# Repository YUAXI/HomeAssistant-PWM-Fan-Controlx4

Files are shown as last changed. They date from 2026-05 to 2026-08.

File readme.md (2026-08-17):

# HomeAssistant-PWM-Fan-Controlx4

<p align="center"><a href="readme.md">中文</a> · <a href="README_EN.md">English</a></p>

一个基于 ESPHome 的 4 路 PWM 风扇控制器，支持 Home Assistant、Web 控制面板和 HTTP REST API。每路风扇都可以独立开关、调速和读取转速；v2.0 固件还支持 DS18B20 温度控制及 LD2402G 毫米波雷达扩展。

## 1. 固件版本与下载

### 1.1 先确认硬件版本

刷写前请先确认主控硬件与固件匹配：

> **成品设备通常采用单核设计，只能刷入 `v1.0 单核` 或任意 `v2.0` 固件。请勿将 `v1.0 双核` 固件刷入单核设备，否则设备将无法启动。**

### 1.2 固件选择

| 固件版本 | 处理器 | 主要功能 | 适用场景 |
|:---|:---:|:---|:---|
| **v1.0 双核** | 双核 | 4 路风扇控制、转速显示、Web、HTTP API、诊断、BLE Proxy | 确认使用双核硬件，且需要较高性能 |
| **v1.0 单核** | 单核 | 4 路风扇控制、转速显示、Web、HTTP API、诊断、BLE Proxy | v1.0 单核硬件，使用 HA 自动化控温 |
| **v2.0 Basic** | 单核 | 基础 4 路风扇控制、转速显示、Web、HTTP API、诊断、BLE Proxy | v2.0 硬件，不使用本地温度和雷达 |
| **v2.0 DS18B20** | 单核 | v2.0 Basic 功能 + 最多 4 个 DS18B20 温度传感器 + 本地自动调速 | 服务器、机柜、NAS 等需要脱离 HA 独立控温的场景 |
| **v2.0 DS18B20+雷达** | 单核 | DS18B20 版本功能 + LD2402G 24GHz 毫米波人体存在检测 | 需要按人体存在状态联动的智能家居场景 |

所有版本均支持：

- 4 路风扇独立 PWM 调速，速度范围为 1-100%，支持完全断电停转。
- 4 路风扇转速（RPM）读取。
- Home Assistant ESPHome 集成、Web 控制面板和 HTTP REST API。
- 运行时间、Wi-Fi 信号、IP 地址、SSID 和 ESPHome 版本等诊断实体。
- 蓝牙代理（BLE Proxy），用于扩展 Home Assistant 的蓝牙覆盖范围。

### 1.3 功能对比

| 功能 | v1.0 双核 | v1.0 单核 | v2.0 Basic | v2.0 DS18B20 | v2.0 + 雷达 |
|:-----|:---:|:---:|:---:|:---:|:---:|
| 4 路 PWM 风扇控制 | ✅ | ✅ | ✅ | ✅ | ✅ |
| 完全断电停转 | ✅ | ✅ | ✅ | ✅ | ✅ |
| 实时转速显示 | ✅ | ✅ | ✅ | ✅ | ✅ |
| Web 界面 / HTTP API | ✅ | ✅ | ✅ | ✅ | ✅ |
| 诊断实体 | ✅ | ✅ | ✅ | ✅ | ✅ |
| 蓝牙代理 | ✅ | ✅ | ✅ | ✅ | ✅ |
| DS18B20 温度控制 | - | - | - | ✅ | ✅ |
| LD2402G 毫米波雷达 | - | - | - | - | ✅ |

### 1.4 下载预编译固件

固件由 GitHub Actions 自动编译并发布，无需手动打包：

[前往 GitHub Releases 下载](https://github.com/YUAXI/HomeAssistant-PWM-Fan-Controlx4/releases)

每个版本包含以下 3 类文件：

| 文件后缀 | 用途 |
|:---|:-----|
| `.firmware.bin` | 常规刷写使用的标准固件 |
| `.firmware.factory.bin` | 完整恢复出厂设置时使用的工厂固件 |
| `.firmware.ota.bin` | 已联网设备的 OTA 升级固件 |

Release 中的版本名称与配置文件对应关系如下：

| Release 名称 | 配置文件 |
|:---|:---|
| `v1.0-dual-core` | `firmware/v1.0/dual-core/config.yaml` |
| `v1.0-single-core` | `firmware/v1.0/single-core/config.yaml` |
| `v2.0-basic` | `firmware/v2.0/single-core/basic/config.yaml` |
| `v2.0-ds18b20` | `firmware/v2.0/single-core/ds18b20/config.yaml` |
| `v2.0-ds18b20-radar` | `firmware/v2.0/single-core/ds18b20-radar/config.yaml` |

### 1.5 自定义编译

需要修改 Wi-Fi、实体名称或其他 ESPHome 配置时，可以直接编辑上表中的 `config.yaml`，然后使用 ESPHome 编译和刷写。所有配置文件都使用 ESP32 DevKit、ESP-IDF 框架；v1.0 单核和 v2.0 固件明确启用了单核运行配置。

## 2. 快速上手

### 2.1 供电

| 供电方式 | 接口 | 电压 | 说明 |
|:---|:-----|:-----|:-----|
| **DC 接口（推荐）** | DC 座 | 12V / 2A 以上 | 正常运行，同时为风扇和 ESP32 供电 |
| Type-C 接口 | USB-C | 5V | 仅用于刷写和调试，不能驱动风扇正常工作 |

### 2.2 首次配网

设备上电后会创建无密码 Wi-Fi 热点 `ESP32-Fan-22810`：

1. 使用手机或电脑连接 `ESP32-Fan-22810`。
2. 浏览器访问 `http://192.168.4.1` 或 `http://esp32pwm22810.local`。
3. 在 Wi-Fi 配置向导中选择目标 Wi-Fi 并输入密码。
4. 设备连接成功后会自动重启。

如果需要跳过首次配网，可以在刷写前于配置文件中预设 `wifi.ssid` 和 `wifi.password`。

### 2.3 刷写固件

使用 Type-C 连接设备和电脑，选择对应硬件的固件，使用 ESPHome 刷写工具或 `esptool` 完成首次刷写。设备联网后可以使用 `.firmware.ota.bin` 进行远程升级。

### 2.4 接入 Home Assistant

先确保已安装 Home Assistant 的 ESPHome 集成：

1. 打开 **设置 → 设备与服务 → 添加集成**，搜索 **ESPHome**。
2. 选择自动发现的 `ESP32 PWM 22810`，或手动输入设备 IP 地址。
3. 输入以下配置文件中的 API 加密密钥并提交：

   ```text
   LqGIGJ3qyRc+6X6hsMe5vAms+Jyh2lOMh1FQu8yyuzk=
   ```

接入后通常会出现以下实体：

| 实体类型 | 数量 | 说明 |
|:---|:----:|:-----|
| 风扇 | 4 个 | 独立开关和 1-100% 调速 |
| 转速传感器 | 4 个 | 单位为 RPM |
| 温度传感器 | 4 个 | 仅 v2.0 DS18B20 及雷达固件，名称为温度 A/B/C/D |
| 蓝牙代理 | 1 个 | BLE Proxy 节点 |
| 诊断实体 | 若干 | 运行时间、Wi-Fi 信号、IP、SSID、ESPHome 版本等 |

### 2.5 Web 控制面板

浏览器访问 `http://设备IP` 即可打开 Web 控制面板，不依赖 Home Assistant。面板可以查看 4 路风扇状态、独立调节风速并查看设备运行信息。

## 3. v2.0 温度与雷达功能

### 3.1 DS18B20 接线

DS18B20 接入 v2.0 板载 **GPIO14** 的 3PIN 排针，使用 1-Wire 总线：

| DS18B20 引脚 | 连接位置 |
|:---:|:---|
| VCC | 3.3V 或 5V |
| GND | GND |
| DATA | GPIO14 |

配置已集成上拉电阻，GPIO14 总线最多可并联 4 个 DS18B20。固件按总线索引将其命名为 **温度 A、温度 B、温度 C、温度 D**。

### 3.2 本地温度调速

本节适用于 `v2.0-ds18b20` 和 `v2.0-ds18b20-radar` 固件。接入设备后，在 Home Assistant 的 **ESP32 PWM 22810** 设备页面中，为每路风扇设置温度源和参数：

| 参数 | 作用 | 默认值 |
|:-----|:-----|:---:|
| 温度源绑定 `F-Src` | 选择未绑定或温度 A/B/C/D | 风扇 1-4 分别绑定 A-D |
| 启控温度 `T-Min` | 温度低于或等于该值时断电停转 | 30°C |
| 满载温度 `T-Max` | 温度高于或等于该值时使用最高风速 | 50°C |
| 最低风速 `F-Min` | 线性调速区间的最低风速 | 0% |
| 最高风速 `F-Max` | 线性调速区间的最高风速 | 100% |

控制逻辑：

```text
温度 ≤ T-Min                   → 断电完全关停风扇
T-Min < 温度 < T-Max           → 按温度线性比例调速
温度 ≥ T-Max                   → 以 F-Max 运行
温度读取异常                    → 保持当前风速和运行状态
```

上述参数支持掉电保持。未绑定温度源的风扇不会执行本地温控逻辑，仍可通过 Home Assistant、Web 或 HTTP API 手动控制。

### 3.3 LD2402G 雷达接口

仅 `v2.0-ds18b20-radar` 固件启用雷达串口：

| 雷达接口 | 控制器接口 |
|:---|:---|
| TX | GPIO4（UART RX） |
| RX | GPIO5（UART TX） |
| 电源 / 地 | v2.0 开发者排针的 5V / GND |

串口速率为 `115200`。雷达固件提供目标存在状态和目标距离实体，并提供最近、最远距离过滤参数，默认范围为 `0.10-1.5 m`。雷达与风扇、温度控制的联动关系可在 Home Assistant 中通过自动化配置。

## 4. Home Assistant 自动化控温

v2.0 DS18B20 固件已经支持本地温控；以下方式适用于所有版本，尤其适合 v1.0，或需要使用 CPU 温度、环境温度等 Home Assistant 外部温度源的场景。

### 4.1 配置步骤

1. 打开 Home Assistant → **自动化与场景 → 创建自动化**。
2. 点击右上角 **更多 → YAML 编辑**。
3. 粘贴下方模板。
4. 将温度传感器和风扇实体 ID 替换为自己的实体后保存。

### 4.2 YAML 模板

```yaml
alias: "通用智能风扇线性调速"
description: "根据温度传感器数值线性控制风扇 PWM 占空比"
mode: restart

trigger:
  - platform: state
    entity_id: sensor.nas_temperature_x86_pkg_temp  # 需要修改

condition:
  - condition: template
    value_template: "{{ is_number(states('sensor.nas_temperature_x86_pkg_temp')) }}"  # 需要修改

action:
  - service: fan.set_percentage
    target:
      entity_id: fan.fan_1  # 需要修改
    data:
      percentage: >
        {% set current_temp = states('sensor.nas_temperature_x86_pkg_temp') | float(0) %}  {# 需要修改 #}
        {% set t_min = 30 %}
        {% set t_max = 50 %}
        {% set f_min = 0 %}
        {% set f_max = 100 %}
        {% if current_temp <= t_min %}
          {{ f_min }}
        {% elif current_temp >= t_max %}
          {{ f_max }}
        {% else %}
          {% set result = ((current_temp - t_min) * (f_max - f_min) / (t_max - t_min) + f_min) %}
          {{ result | round(0) | int }}
        {% endif %}
```

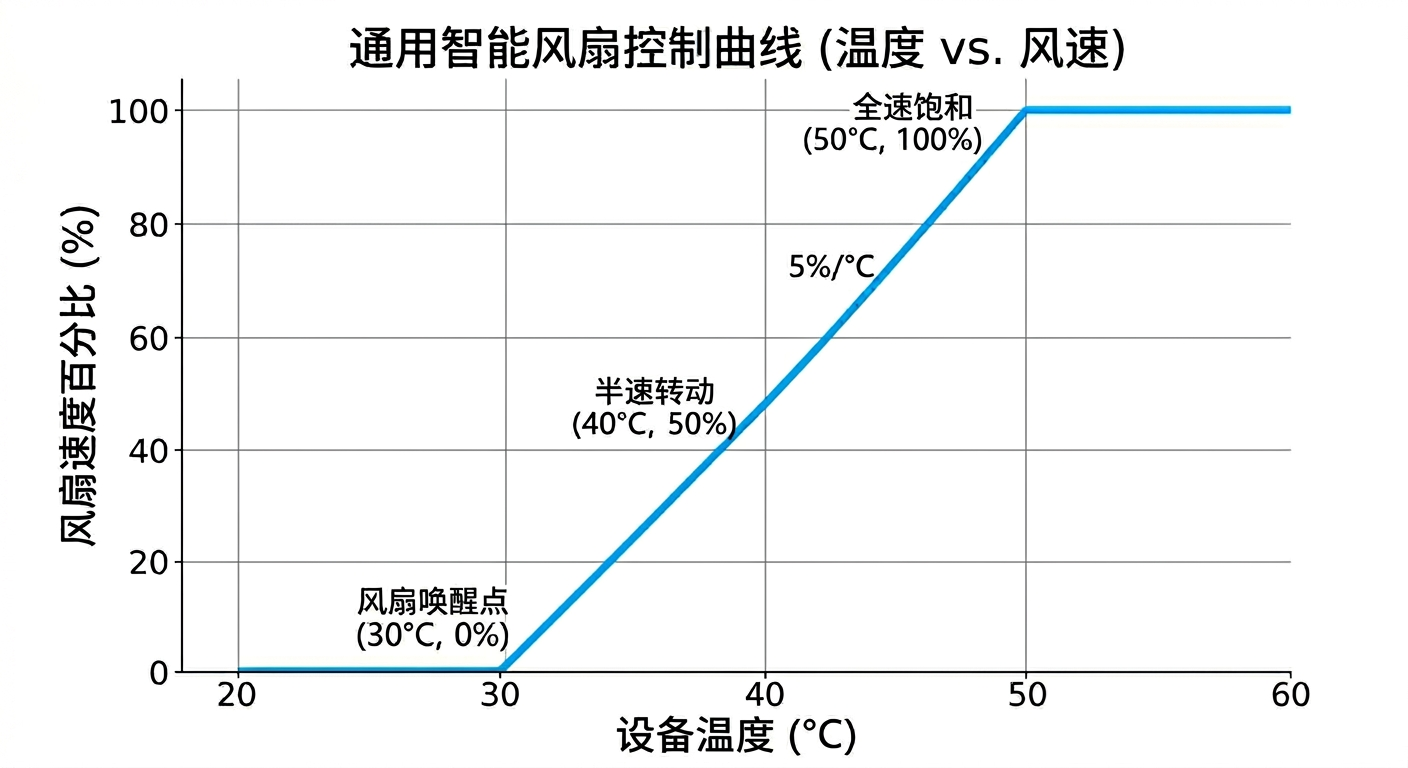
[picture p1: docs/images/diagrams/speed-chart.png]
温度与风速关系


常见温度源示例：

| 温度来源 | 获取方式 | 示例实体 ID |
|:---|:---|:---|
| 电脑 / 服务器 CPU | Glances 集成 | `sensor.nas_temperature_x86_pkg_temp` |
| 温湿度传感器 | Zigbee2MQTT / ZHA | `sensor.temperature_humidity_sensor_temperature` |
| 空调 / 暖气 | 智能空调集成 | `climate.living_air_conditioner` |
| 群晖 NAS | Synology DSM 集成 | `sensor.synology_disk_1_temperature` |
| 其他 ESPHome 设备 | ESPHome 集成 | 按实际设备填写 |

## 5. HTTP REST API

项目内置 Web Server，可以通过局域网 HTTP 请求控制风扇或读取传感器。控制命令使用 **POST**，状态读取使用 **GET**。实体名称包含中文时，URL 必须进行 UTF-8 编码。

### 5.1 实体与路径示例

ESPHome 会根据配置中的 `name` 自动生成实体 ID。以下为第 1 路风扇示例：

| 实体名称 | entity_id | URL 路径 |
|:---|:---|:---|
| 风扇 1 | `fan.风扇_1` | `/fan/%E9%A3%8E%E6%89%87_1` |
| 风扇 1 转速 | `sensor.风扇_1_转速` | `/sensor/%E9%A3%8E%E6%89%87_1_%E8%BD%AC%E9%80%9F` |

如需调用其他风扇，请按配置中的实体名称替换路径。也可以优先使用 Home Assistant 的 `fan.set_percentage` 服务，避免手动处理中文 URL。

### 5.2 Python 示例

```python
import requests
from urllib.parse import quote

base = "http://10.0.20.83"  # 替换为设备 IP

# 开启 2 号风扇并设置为 50%
requests.post(f"{base}/fan/{quote('风扇 2')}/turn_on", params={"speed_level": 50})

# 关闭 2 号风扇
requests.post(f"{base}/fan/{quote('风扇 2')}/turn_off")

# 读取 1 号风扇转速
response = requests.get(f"{base}/sensor/{quote('风扇 1 转速')}")
if response.status_code == 200:
    print("当前转速:", response.json()["value"])
```

## 6. 硬件资料与接口

### 6.1 硬件文件

v2.0 为推荐硬件版本：

| 类型 | v2.0 文件 | v1.0 文件 |
|:-----|:---|:---|
| PCB Gerber | [gerber.zip](./hardware/v2.0/pcb/gerber.zip) | [gerber.zip](./hardware/v1.0/pcb/gerber.zip) |
| BOM 清单 | [bom.xlsx](./hardware/v2.0/pcb/bom.xlsx) | [bom.xlsx](./hardware/v1.0/pcb/bom.xlsx) |
| 立创 EDA 工程 | [project.epro2](./hardware/v2.0/pcb/project.epro2) | [project.epro2](./hardware/v1.0/pcb/project.epro2) |
| 外壳主体 | [case.STEP](./hardware/v2.0/3d-models/print/case.STEP) | [case.step](./hardware/v1.0/3d-models/print/case.step) |
| 上盖 | [top-cover.STEP](./hardware/v2.0/3d-models/print/top-cover.STEP) | [top-cover.step](./hardware/v1.0/3d-models/print/top-cover.step) |

### 6.2 风扇接口映射

| 风扇 | PWM 输出 | Tach 转速输入 | 电源管理 |
|:----:|:---:|:---:|:---:|
| Fan1 | GPIO16 | GPIO32 | GPIO21 |
| Fan2 | GPIO17 | GPIO33 | GPIO22 |
| Fan3 | GPIO18 | GPIO25 | GPIO23 |
| Fan4 | GPIO19 | GPIO26 | GPIO13 |

v2.0 额外接口：

| 接口 | 说明 |
|:-----|:-----|
| GPIO14（3PIN 排针） | DS18B20 1-Wire 温度总线 |
| 4PIN 开发者排针（5V / GND / GPIO5 / GPIO4） | 可扩展 LD2402G 雷达、RS485 等外设 |

### 6.3 硬件设计要点

- **风扇电源控制**：使用 `TPS22810DBVR` 直接切断风扇供电，实现真正的完全停转。
- **电源方案**：12V → 5V（`TPS5430DDAR` DC-DC）→ 3.3V（`AMS1117-3.3`）。
- **USB 转串口**：板载 `CH340C`，通过 Type-C 连接电脑刷写和调试。

## 7. 项目展示

<div style="text-align: center;">
  <table>
    <tr>
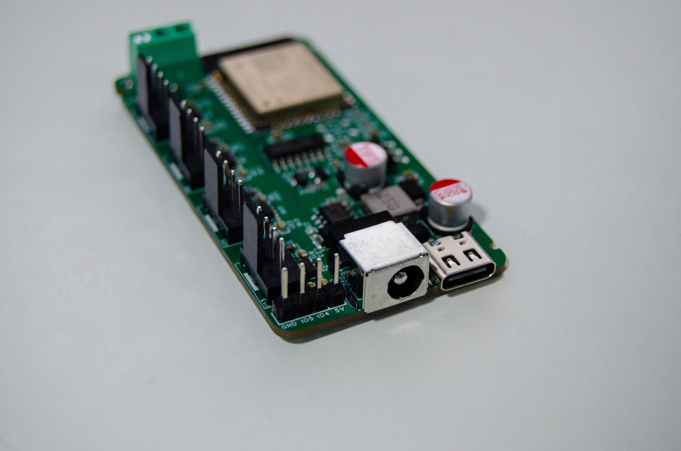
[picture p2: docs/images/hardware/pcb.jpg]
PCB 实物图
      <td width="25%" style="padding: 10px;"></td>
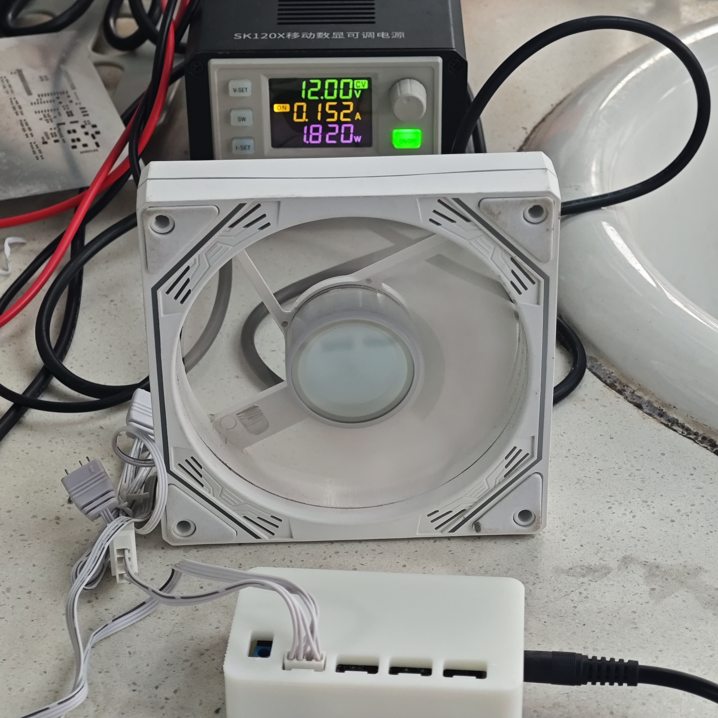
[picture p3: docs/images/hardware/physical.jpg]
测试图
      <td width="25%" style="padding: 10px;"></td>
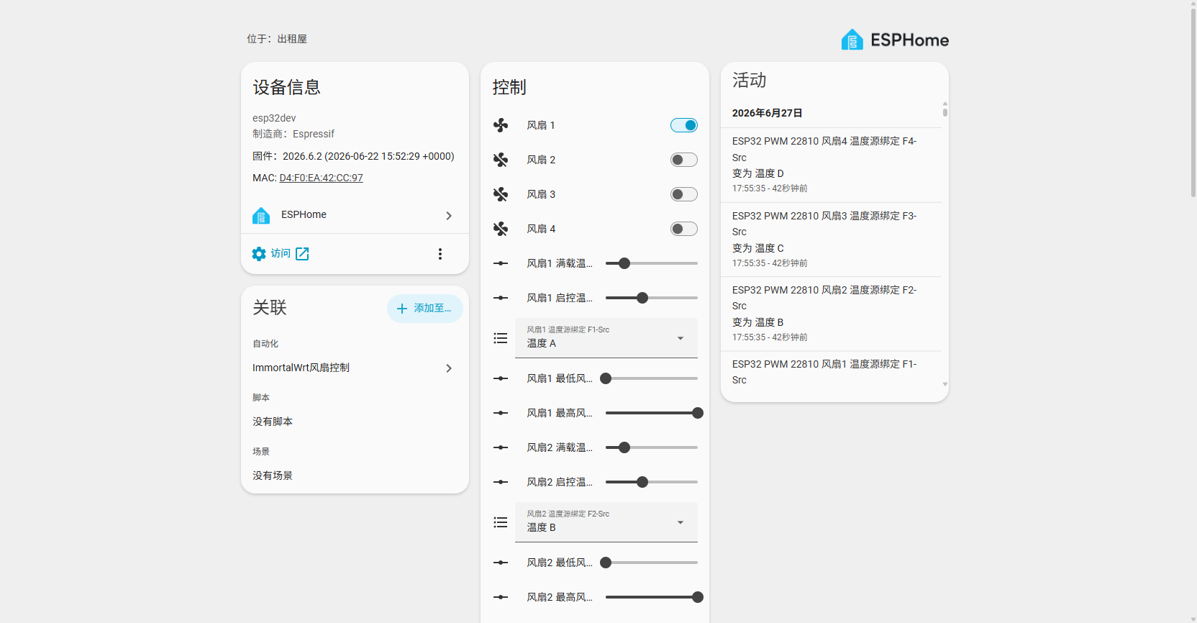
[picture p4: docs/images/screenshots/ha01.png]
Home Assistant 控制界面
      <td width="25%" style="padding: 10px;"></td>
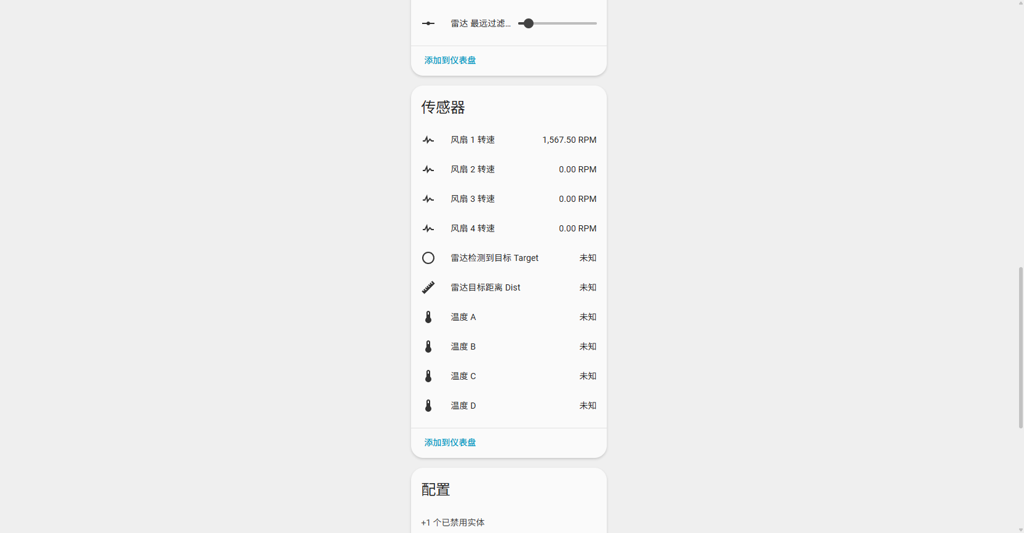
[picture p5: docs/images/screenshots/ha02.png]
Home Assistant 设备诊断信息
      <td width="25%" style="padding: 10px;"></td>
    </tr>
  </table>
</div>

## 8. 更新记录

| 日期 | 更新内容 |
|:-----|:---|
| 2026-08-16 | 自动调速时温度低于或等于 `T-Min` 时断电停转，温度恢复后自动重启风扇。 |
| 2026-07-10 | DS18B20 读取异常时保持当前风速，移除异常时强制全速保护。 |
| 2026-07-01 | 全版本增加蓝牙代理；CI 自动编译并发布 Release；移除仓库中的预编译固件。 |
| v2.0 | 增加 DS18B20 温度控制、毫米波雷达固件和 v2.0 硬件设计。 |
| v1.0 | 提供 Web 界面、HTTP REST API 和诊断实体。 |

## 9. 支持与许可证

交流群二维码不再维护。

<div style="text-align: center;">
  <table>
    <tr>
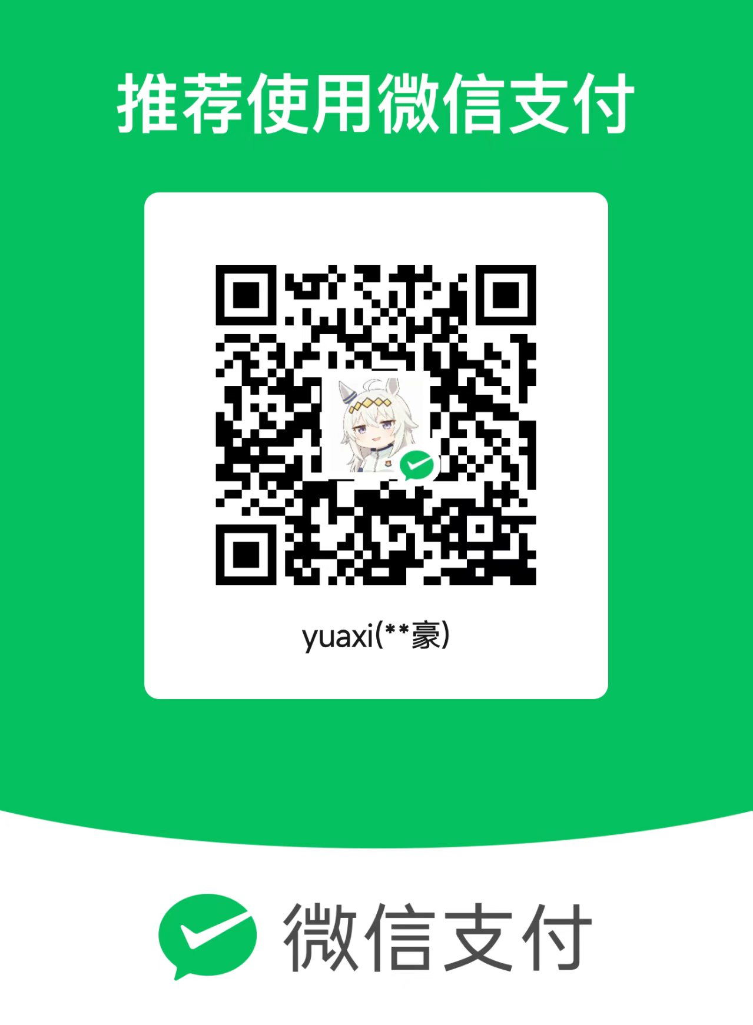
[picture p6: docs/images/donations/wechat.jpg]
微信打赏
      <td width="50%" style="padding: 10px;"><p><small>微信</small></p></td>
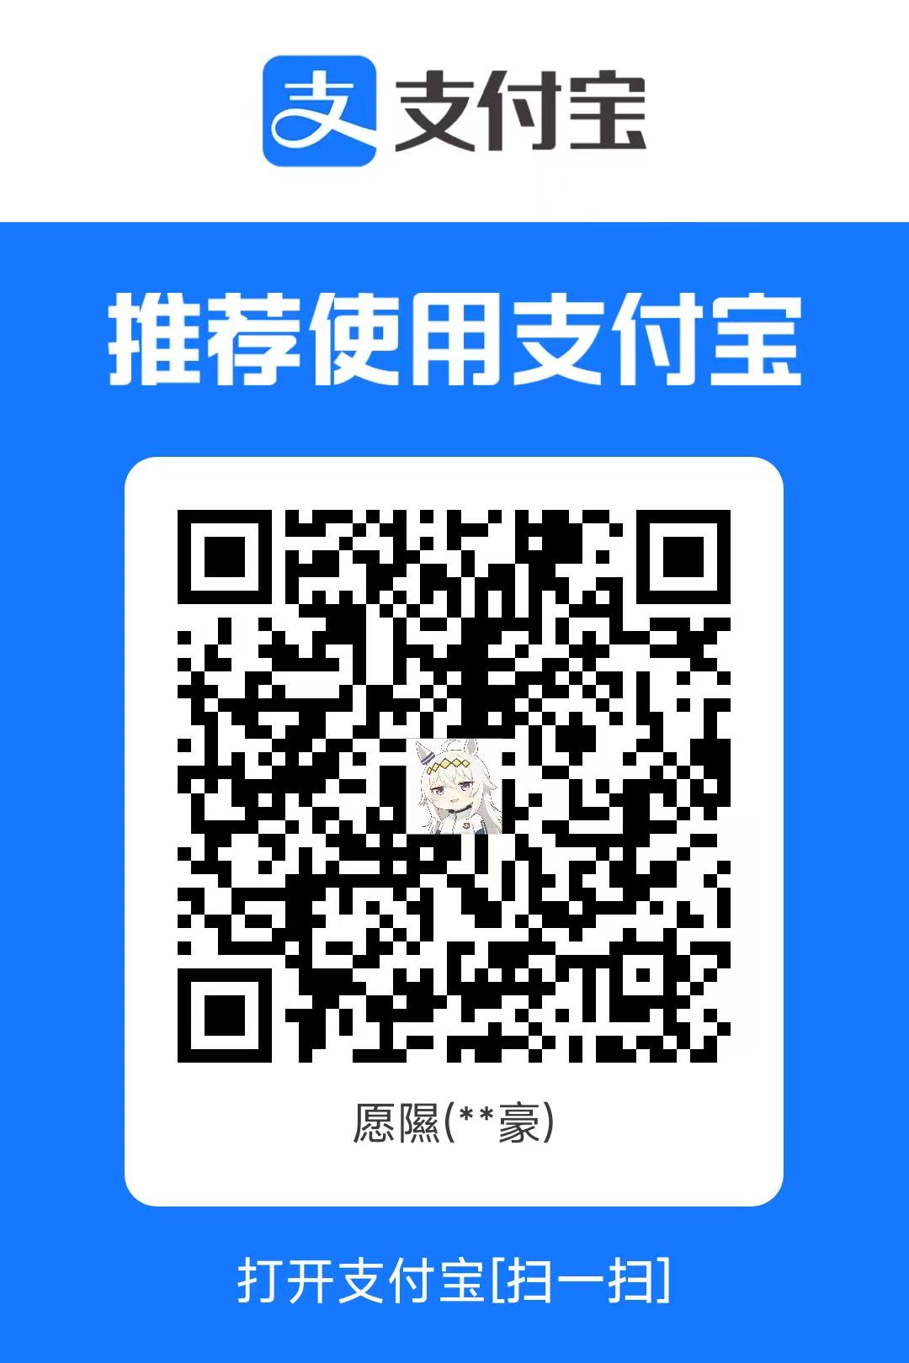
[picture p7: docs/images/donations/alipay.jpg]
支付宝打赏
      <td width="50%" style="padding: 10px;"><p><small>支付宝</small></p></td>
    </tr>
  </table>
</div>

本项目采用 [MIT License](./LICENSE) 开源许可证。

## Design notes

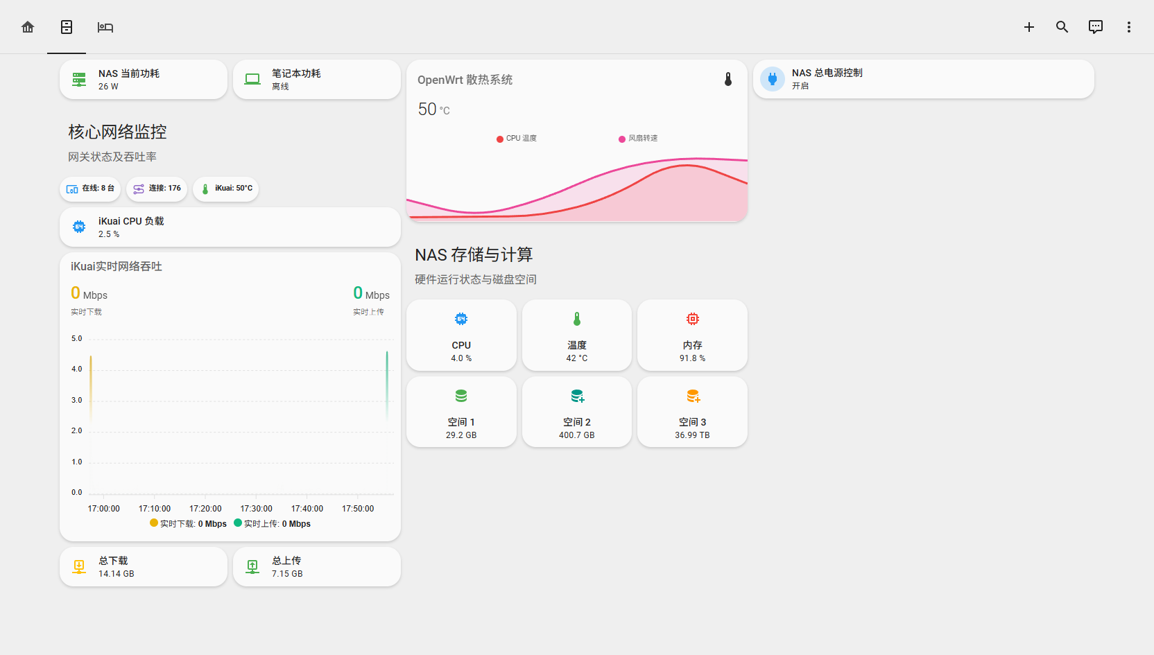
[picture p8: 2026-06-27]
docs/images/screenshots/ha03.png

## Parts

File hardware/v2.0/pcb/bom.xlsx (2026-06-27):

No. | Quantity | Comment | Designator | Footprint | Value | Manufacturer Part | Manufacturer | Supplier Part | Supplier
1 | 1 | 10nF | C1 | C0603 | 10nF | 0603B103K500NT | FH(风华) | C57112 | LCSC
2 | 2 | 220uF | C2,C12 | CAP-SMD_BD6.3-L6.6-W6.6-LS7.2-FD | 220uF | PM101M016E058PTR | CapXon(丰宾) | C2858381 | LCSC
3 | 5 | 10uF | C3,C4,C6,C9,C10 | C0603 | 10uF | CL10A106MA8NRNC | SAMSUNG(三星) | C96446 | LCSC
4 | 17 | 100nF | C5,C7,C8,C11,C13,C14,C15,C16,C17,C18,C19,C20,C21,C22,C23,C24,C25 | C0603 | 100nF | CC0603KRX7R9BB104 | YAGEO(国巨) | C14663 | LCSC
5 | 3 | SS34 | D1,D2,D3 | SMA_L4.3-W2.6-LS5.2-RD |  | SS34 | MDD(辰达半导体) | C8678 | LCSC
6 | 1 | DC-044A-A200 | DC1 | DC-IN-TH_DC-044A-20A |  | DC-044A-A200 | XUNPU(讯普) | C720575 | LCSC
7 | 1 | HDR-M_2.54_1x4P | H1 | HDR-TH_4P-P2.54-V-M |  |  |  | C492403
8 | 2 | S8050(0.5A) | Q4,Q6 | SOT-23-3_L2.9-W1.3-P1.90-LS2.4-BR |  | S8050(0.5A) | EIC | C3014350 | LCSC
9 | 13 | 10kΩ | R1,R2,R3,R5,R6,R7,R8,R9,R10,R11,R12,R13,R14 | R0603 | 10kΩ | 0603WAF1002T5E | UNI-ROYAL(厚声) | C25804 | LCSC
10 | 2 | 3.24K | R4,R15 | R0603 | 3.24K
11 | 2 | TS-1088-AR02016 | SW1,SW2 | SW-SMD_L3.9-W3.0-P4.45 |  | TS-1088-AR02016 | XUNPU(讯普) | C720477 | LCSC
12 | 1 | TPS5430DDAR | U1 | ESOP-8_L4.9-W3.9-P1.27-LS6.0-TL-EP |  | TPS5430DDAR | TI(德州仪器) | C9864 | LCSC
13 | 1 | AMS1117-3.3 | U2 | SOT-223-3_L6.5-W3.5-P3.05-LS7.0 |  | AMS1117-3.3 | TWGMC(台湾迪嘉) | C5250992 | LCSC
14 | 1 | 15uH | U3 | IND-SMD_L7.2-W6.6_GPSR07X0 | 15uH | CYA0650-22UH | SHOU HAN(首韩) |  | LCSC
15 | 1 | ESP32-WROOM-32-N4 | U4 | WIFIM-SMD_ESP32-WROOM-32-N4 |  | ESP32-WROOM-32-N4 | ESPRESSIF(乐鑫) | C82899 | LCSC
16 | 1 | CH340C | U5 | SOP-16_L10.0-W3.9-P1.27-LS6.0-BL |  | CH340C | WCH(南京沁恒) | C84681 | LCSC
17 | 4 | TPS22810DBVR | U6,U8,U10,U12 | SOT-23-6_L2.9-W1.6-P0.95-LS2.8-BL |  | TPS22810DBVR | TI(德州仪器) | C205990 | LCSC
18 | 4 | 风扇4Pin插座 | U7,U9,U11,U13 | 风扇4PIN
19 | 1 | DB301V-3.5-3P-GN-S | U14 | CONN-TH_DB301V-3.5-3P-GN |  | DB301V-3.5-3P-GN-S | DORABO(地博电气) | C695630 | LCSC
20 | 1 | TYPE-C 16PIN 2MD(073) | USB1 | USB-C-SMD_TYPE-C-6PIN-2MD-073 |  | TYPE-C 16PIN 2MD(073) | SHOU HAN(首韩) | C2765186 | LCSC

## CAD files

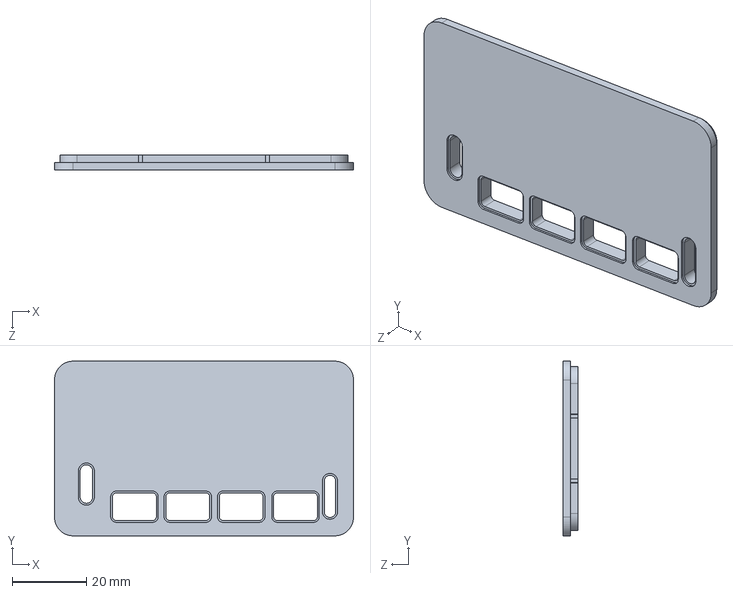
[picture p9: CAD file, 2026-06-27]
hardware/v2.0/3d-models/print/top-cover.STEP
80.4 x 47.0 x 4.00 mm

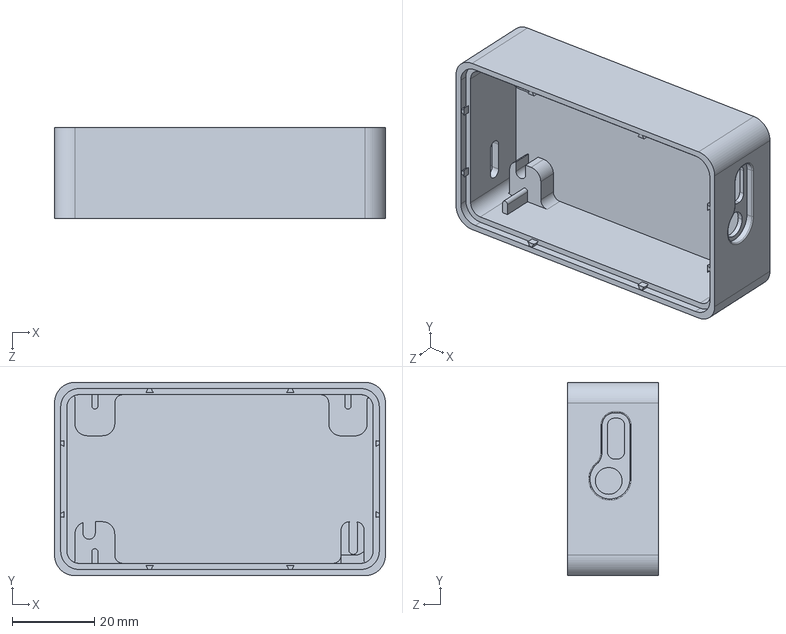
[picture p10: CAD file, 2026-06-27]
hardware/v2.0/3d-models/print/case.STEP
80.4 x 47.0 x 22.0 mm

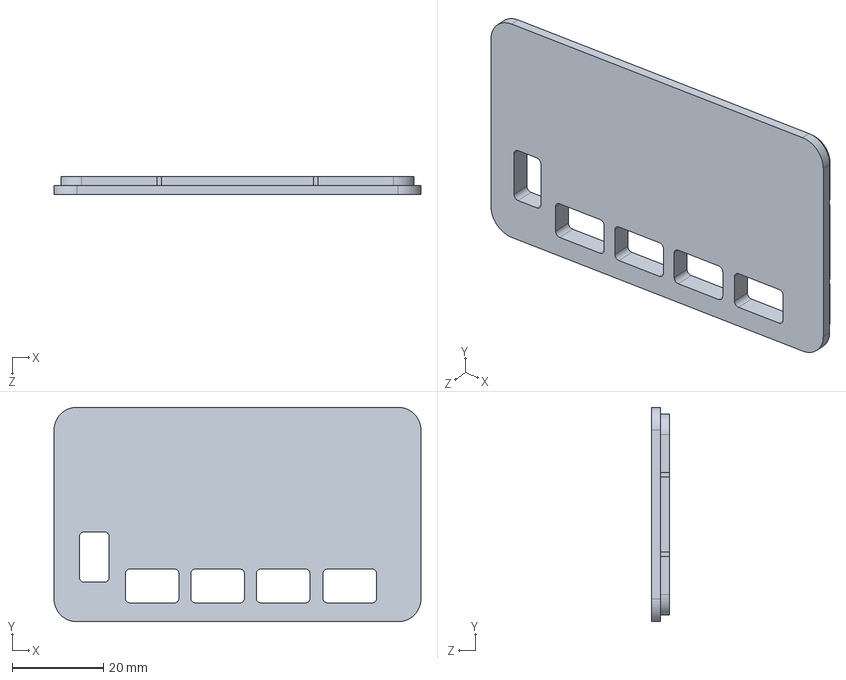
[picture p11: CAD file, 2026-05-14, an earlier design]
hardware/v1.0/3d-models/print/top-cover.step
80.4 x 47.0 x 4.00 mm

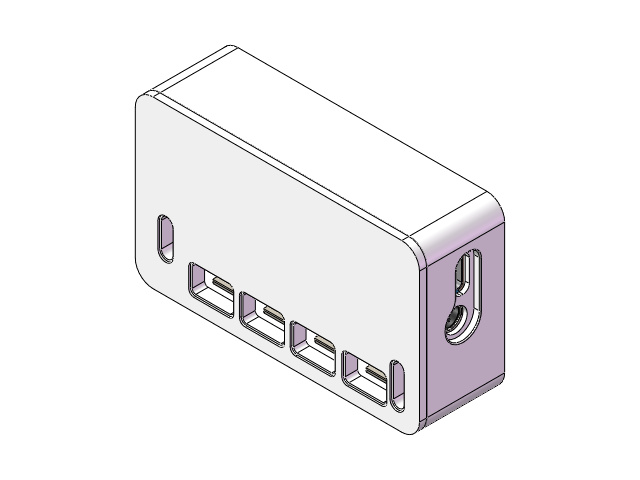
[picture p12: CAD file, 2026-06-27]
hardware/v2.0/3d-models/source/assembly.SLDASM
top-cover
case
CAP-SMD_BD6.3-L6.6-W6.6-LS7.2-FD~CAP-SMD_BD6.3-L6.6-W6.6-LS7.2-FD~qhwz.step x 2
IND-SMD_L7.2-W6.6_GPSR07X0~IND-SMD_L7.2-W6.6-H3.0_GPSR07X0~RW3T.step
ESOP-8_L4.9-W3.9-P1.27-LS6.0-TL-EP~ESOP-8_L4.9-W3.9-P1.27-LS6.0-TL-EP~MRIl.step
DC-IN-TH_DC-044A-20A~DC-IN-TH_DC-044A-20A~IdZU.step
SOT-223-3_L6.5-W3.5-P3.05-LS7.0~SOT-223-3_L6.5-W3.5-P3.05-LS7.0~3Vlb.step
R0603~R0603~Ejyd.step x 15
USB-C-SMD_TYPE-C-6PIN-2MD-073~USB-C-SMD_TYPE-C-6PIN-2MD-073~PAtE.step
C0603~C0603_L1.6-W0.8-H0.8~XpD2.step x 23
SMA_L4.3-W2.6-LS5.2-RD~SMA_L4.3-W2.6-LS5.2-RD~yZNh.step x 3
HDR-TH_4P-P2.54-V-M~HDR-TH_4P-P2.54-M-LI-1X4P~ZgB5.step
SOT-23-3_L2.9-W1.3-P1.90-LS2.4-BR~SOT-23-3P_L2.9-W1.3-H1.0-LS2.4-P0.95~SnWO.step x 2
SOT-23-6_L2.9-W1.6-P0.95-LS2.8-BL~SOT-23-6_L2.9-W1.6-H1.5-LS2.8-P0.95~LPVG.step x 4
SW-SMD_L3.9-W3.0-P4.45~SW-SMD_L3.9-W2.9-H2.0-LS4.8~mZxP.step x 2
______4PIN~CONN-TH_M2510V-04P~UagZ.step x 4
SOP-16_L10.0-W3.9-P1.27-LS6.0-BL~SOP-16_L9.9-W3.9-H1.5-LS6.0-P1.27~UwFI.step
WIFIM-SMD_ESP32-WROOM-32-N4~WIFIM-SMD_ESP32-WROOM-32-N4~UbdI.step
CONN-TH_DB301V-3.5-3P-GN~CONN-TH_DB301V-3.5-3P-GN~7HpH.step
Board~OeKS.step

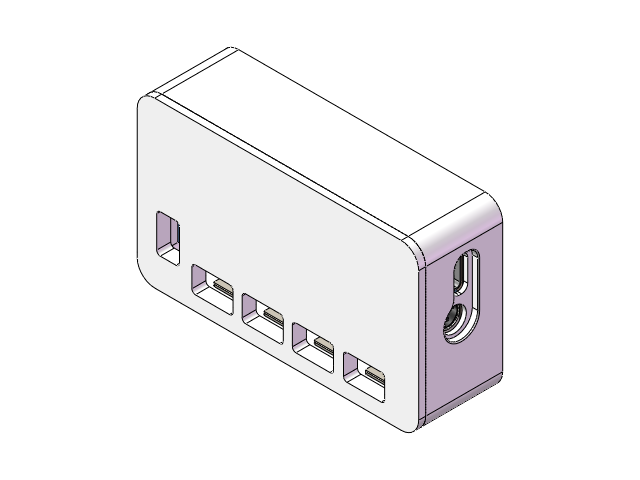
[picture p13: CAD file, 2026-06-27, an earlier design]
hardware/v1.0/3d-models/source/assembly.SLDASM
USB-C-SMD_TYPE-C-6PIN-2MD-073~USB-C-SMD_TYPE-C-6PIN-2MD-073~xnjJ.step
SOT-223-3_L6.5-W3.5-P3.05-LS7.0~SOT-223-3_L6.5-W3.5-P3.05-LS7.0~ZwZV.step
C0603~C0603_L1.6-W0.8-H0.8~ggr9.step x 22
DC-IN-TH_DC-044A-20A~DC-IN-TH_DC-044A-20A~cYJv.step
SW-SMD_L3.9-W3.0-P4.45~SW-SMD_L3.9-W2.9-H2.0-LS4.8~LN4r.step x 2
ESOP-8_L4.9-W3.9-P1.27-LS6.0-TL-EP~ESOP-8_L4.9-W3.9-P1.27-LS6.0-TL-EP~HWgo.step
HDR-TH_3P-P2.54-V-M~HDR-TH_3P-P2.54-M-LI-1X3P~kQFJ.step
______4PIN~CONN-TH_M2510V-04P~ZBu1.step x 4
WIFIM-SMD_ESP32-WROOM-32-N4~WIFIM-SMD_ESP32-WROOM-32-N4~uz2J.step
CONN-TH_P5.00_KF301-5.0-2P~CONN-TH_P5.00_KF301-5.0-2P~xQkq.step
SOT-23-3_L2.9-W1.3-P1.90-LS2.4-BR~SOT-23-3P_L2.9-W1.3-H1.0-LS2.4-P0.95~obR9.step x 2
R0603~R0603~5TKr.step x 14
IND-SMD_L7.2-W6.6_GPSR07X0~IND-SMD_L7.2-W6.6-H3.0_GPSR07X0~X1Os.step
SOP-16_L10.0-W3.9-P1.27-LS6.0-BL~SOP-16_L9.9-W3.9-H1.5-LS6.0-P1.27~eOWs.step
CAP-SMD_BD6.3-L6.6-W6.6-LS7.2-FD~CAP-SMD_BD6.3-L6.6-W6.6-LS7.2-FD~YAAd.step x 2
SMA_L4.3-W2.6-LS5.0-FD~SMA_L4.3-W2.6-LS5.0-FD~hx3n.step x 2
SMA_L4.3-W2.6-LS5.2-RD~SMA_L4.3-W2.6-LS5.2-RD-1~7yL3.step x 2
SOT-23-6_L2.9-W1.6-P0.95-LS2.8-BL~SOT-23-6_L2.9-W1.6-H1.5-LS2.8-P0.95~59r2.step x 4
Board~2JPI.step
壳体
顶盖

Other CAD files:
hardware/v1.0/3d-models/print/case.step
hardware/v1.0/3d-models/source/case.SLDPRT
hardware/v1.0/3d-models/source/top-cover.SLDPRT
hardware/v2.0/3d-models/source/case.SLDPRT
hardware/v2.0/3d-models/source/top-cover.SLDPRT

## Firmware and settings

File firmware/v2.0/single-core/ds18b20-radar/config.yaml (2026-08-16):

esphome:
  name: esp32pwm22810
  friendly_name: ESP32 PWM 22810
  # 上电初始化
  on_boot:
    priority: -100
    then:
      - logger.log: "正在发送激活指令给 LD2402G..."
      - uart.write: [0x55, 0x5A, 0x02, 0x01, 0xAA] 
      - delay: 200ms
      - uart.write: [0x55, 0x01, 0x01, 0x00, 0xAA]

esp32:
  board: esp32dev
  variant: ESP32 
  framework:
    type: esp-idf
    sdkconfig_options:
      CONFIG_FREERTOS_UNICORE: "y"
      CONFIG_ESP_SYSTEM_PANIC_PRINT_REBOOT: "y"

logger:
  level: INFO

api:
  encryption:
    key: "LqGIGJ3qyRc+6X6hsMe5vAms+Jyh2lOMh1FQu8yyuzk="

ota:
  - platform: esphome
    password: "4283bb50a8cd66774ce91d2c9d412cf2"

wifi:
  ap:
    ssid: "ESP32-Fan-22810"
    password: "" 

captive_portal:

esp32_ble_tracker:

bluetooth_proxy:
  active: true

web_server:
  port: 80

# ==========================================
# 24G 毫米波雷达硬件串口及动态调参抗干扰算法
# ==========================================
uart:
  - id: radar_uart
    tx_pin: GPIO5
    rx_pin: GPIO4
    baud_rate: 115200
    debug:
      direction: RX
      dummy_receiver: true
      sequence:
        - lambda: |-
            static std::string line_buffer = "";
            static float last_dist = -1.0f;
            static uint32_t last_change_time = 0;
            
            for (auto val : bytes) {
              if (val == 0x0A) { // 遇到换行符
                int dist_cm = -1;
                if (sscanf(line_buffer.c_str(), "distance:%d", &dist_cm) == 1) {
                  float current_m = dist_cm / 100.0f;
                  
                  // 从 HA 获取用户实时调节的区间限制（单位转成米进行对比）
                  float min_limit = id(radar_min_dist).state;
                  float max_limit = id(radar_max_dist).state;

                  // 【动态抗干扰规则 1】：卡死用户自定义的有效距离区间
                  if (current_m < min_limit || current_m > max_limit) {
                    id(radar_target).publish_state(false);
                    id(radar_dist).publish_state(NAN);
                  } 
                  else {
                    // 【动态抗干扰规则 2】：抗静态震动/数据锁死
                    if (std::abs(current_m - last_dist) > 0.01f) { 
                      last_dist = current_m;
                      last_change_time = millis();
                    }
                    
                    // 如果读数在自定义区间内死卡超过 5 秒，判定为固定伪目标（如无人时的特定反射）
                    if (millis() - last_change_time > 5000) { 
                      id(radar_target).publish_state(false);
                      id(radar_dist).publish_state(NAN);
                    } else {
                      // 合法移动目标
                      id(radar_target).publish_state(true);
                      id(radar_dist).publish_state(current_m);
                    }
                  }
                }
                line_buffer.clear();
              } else if (val != 0x0D) {
                line_buffer += (char)val;
              }
            }

# 1-Wire 单总线
one_wire:
  - platform: gpio
    pin: GPIO14

output:
  - platform: ledc
    pin: GPIO16
    id: fan1_pwm
    frequency: 25000Hz
  - platform: ledc
    pin: GPIO17
    id: fan2_pwm
    frequency: 25000Hz
  - platform: ledc
    pin: GPIO18
    id: fan3_pwm
    frequency: 25000Hz
  - platform: ledc
    pin: GPIO19
    id: fan4_pwm
    frequency: 25000Hz

switch:
  - platform: gpio
    pin: GPIO21
    id: fan1_pwr
    internal: true
    restore_mode: ALWAYS_OFF
  - platform: gpio
    pin: GPIO22
    id: fan2_pwr
    internal: true
    restore_mode: ALWAYS_OFF
  - platform: gpio
    pin: GPIO23
    id: fan3_pwr
    internal: true
    restore_mode: ALWAYS_OFF
  - platform: gpio
    pin: GPIO13
    id: fan4_pwr
    internal: true
    restore_mode: ALWAYS_OFF

# ==========================================
# HA 自行绑定下拉菜单
# ==========================================
select:
  - platform: template
    name: "风扇1 温度源绑定 F1-Src"
    id: f1_source
    optimistic: true
    options:
      - "未绑定"
      - "温度 A"
      - "温度 B"
      - "温度 C"
      - "温度 D"
    initial_option: "温度 A"
    restore_value: true

  - platform: template
    name: "风扇2 温度源绑定 F2-Src"
    id: f2_source
    optimistic: true
    options:
      - "未绑定"
      - "温度 A"
      - "温度 B"
      - "温度 C"
      - "温度 D"
    initial_option: "温度 B"
    restore_value: true

  - platform: template
    name: "风扇3 温度源绑定 F3-Src"
    id: f3_source
    optimistic: true
    options:
      - "未绑定"
      - "温度 A"
      - "温度 B"
      - "温度 C"
      - "温度 D"
    initial_option: "温度 C"
    restore_value: true

  - platform: template
    name: "风扇4 温度源绑定 F4-Src"
    id: f4_source
    optimistic: true
    options:
      - "未绑定"
      - "温度 A"
      - "温度 B"
      - "温度 C"
      - "温度 D"
    initial_option: "温度 D"
    restore_value: true
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

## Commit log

2026-05-14 upload model and pcb
    [壳体.SLDPRT, 壳体.STEP, 顶盖.SLDPRT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]
2026-05-14 upload gerber and bom file
    [BOM_Board1_PCB1_2026-05-14.xlsx, PickAndPlace_PCB1_2026_05_14.xlsx]
2026-05-21 Correct the direction of the diode
    [BOM_Board1_PCB1_2026-05-14.xlsx, BOM_Board1_PCB1_2026-05-21.xlsx, PickAndPlace_PCB1_2026_05_14.xlsx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]
2026-06-02 Update README
    Add encryption key for PWM fan controller project.
2026-06-13 Update fan control section numbers in readme
2026-06-27 chore: 重构项目结构，新增 v2.0 硬件/固件，更新 README 文档
    [BOM_Board1_PCB1_2026-05-21.xlsx, PickAndPlace_PCB1_2026_05_21.xlsx, assembly.SLDASM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]
2026-07-01 feat: 全版本添加蓝牙代理功能，重构 README 文档
    - 为所有5个固件版本添加 esp32_ble_tracker 和 bluetooth_proxy 配置
    - 重整 README 结构：功能对比表、简化快速上手指南、消除重复内容
    - 新增 2026-07-01 更新日志
2026-07-01 refactor: 实体名称改为英文简化 API 路径，更新 README
    - 所有 YAML 实体 name 改为英文（如 Fan 1、Fan 1 RPM），friendly_name 保留中文
    - README API 部分新增实体名称对照表，简化 URL 示例
    - 修正 README 中关于 DS18B20 和 v2.0 接口的描述
    - 删除二创项目栏
    [config.yaml]
2026-07-01 ci: 添加 GitHub Actions 自动编译固件并发布 Release
    每次推送到 master 或手动触发时自动编译全部 5 个版本固件，
    编译完成后自动创建 GitHub Release 并上传所有固件文件。
2026-07-01 fix: 移除不支持的 friendly_name/object_id，恢复中文 name
    ESPHome 2026.6.4 不支持组件级 friendly_name 和 object_id，
    回退为中文 name 方案（HA 显示中文，API 路径需 URL 编码）。
    README API 部分同步更新，提供 Python URL 编码示例。
    [config.yaml]
2026-07-01 fix: 修复 text_sensor 缩进错误导致 YAML 解析失败
    [config.yaml]
2026-07-01 ci: 修复 release 构建，简化固件收集和下载流程
2026-07-01 ci: Release 以日期命名，仅发布编译好的 bin 文件
2026-07-01 ci: 修复 Release 流程，简化 artifact 下载逻辑
2026-07-01 ci: 修复固件收集路径，改用 find 避免 dotfile glob 问题
2026-07-01 ci: 添加固件路径调试，尝试多个可能输出目录
2026-07-01 ci: 恢复 release 流程，固件输出路径兼容多个可能目录
2026-07-01 ci: 添加固件路径调试，搜索全盘查找编译产物
2026-07-01 ci: 修复固件收集路径，使用 YAML 同目录下的 .esphome
2026-07-01 chore: 移除仓库中预编译固件，固件迁移至 GitHub Releases
2026-07-01 docs: 版本选择表移除本地固件链接，指引用户前往 Releases 下载
2026-07-01 docs: 重写固件版本说明板块，新增 Release 文件名对照表
2026-07-10 fix: DS18B20温度读取异常时改为保持当前风速，移除全速保护机制
2026-07-29 docs: 新增英文版 README 及中英文语言切换
2026-08-16 feat: 温度低于起控温度时断电完全关停风扇，温度恢复后自动重启
2026-08-16 fix: 修复FanCall编译错误，turn_off/turn_on改为set_state，select.state改为current_option
2026-08-17 docs: 重整中文 README 文档结构
2026-08-17 docs: 同步英文 README 文档结构
2026-10-14 feat: 固件启用 name_add_mac_suffix，同一份固件可刷多台设备
    - 5 个固件配置启用 MAC 后缀命名，设备名变为 esp32pwm22810-<MAC后3字节>，多台设备可在 HA 分别接入，不再触发名称冲突覆盖
    - README 新增「多台设备与设备命名」(1.6) 与「多台设备同时接入」(2.6)，更新配网、刷写、设备页面说明
    - README 项目展示图移至顶部，章节重新编号
    - Release 说明补充多设备刷写提示
    - 补充 ds18b20 构建目录的 .gitignore
2026-11-09 docs: 新增中英双语 Wiki 与一键发布工具
    - docs/wiki/：13 个主题 × 中英双语（26 页），含导航、侧边栏与编写约定
    覆盖快速上手、固件版本、实体参考、温度控制、毫米波雷达、HTTP API、
    HA 自动化、硬件资料、故障排查、FAQ、开发指南与更新记录
    - scripts/sync-wiki.ps1 / sync-wiki.sh：摊平成 GitHub Wiki 布局
    （Page.md / Page-EN.md / 合并 _Sidebar.md）后 clone → commit → push，
    支持 -OutputDir 预览与 -NoPush；两个脚本输出逐字节一致
    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
